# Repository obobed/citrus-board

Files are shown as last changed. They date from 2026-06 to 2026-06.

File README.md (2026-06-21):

# Citrus Board
A RP2350 based devboard with LiPO and HSTX support!

## Why I made this + features
I made this since I wanted an alternative to the mainstream RP2350/2040 boards (like the xiaos), but with support for the more niche features of the chip that aren't exposed on almost all of them, like HSTX ([page 1203](https://pip-assets.raspberrypi.com/categories/1214-rp2350/documents/RP-008373-DS-2-rp2350-datasheet.pdf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)), which allows you to easily add an external display (or even camera) without sacrificing a lot the small computing power of the small chip, or even LiPo support (although most boards have it (except for the Raspberry Pi Pico), many don't have a dedicated charging IC to both support the chip's usage and to charge the battery at the same time). Additionally, it has 26 pins, indicator LEDs for charging and power, the HSTX 22pin ribbon cable terminal (which can be used with libraries like [this](https://github.com/adafruit/Adafruit-DVI-HSTX) from Adafruit) and a debug connector that is exactly compatible with the oficial [Raspberry Pi Debug Probe
](https://www.raspberrypi.com/documentation/microcontrollers/debug-probe.html).

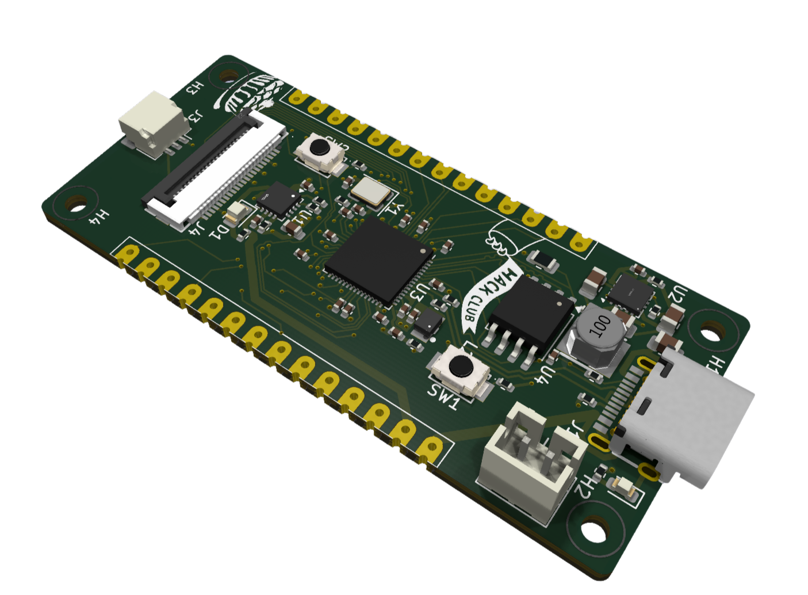
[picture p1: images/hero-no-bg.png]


## Repo Structure
* [/pcb](/pcb) - My KiCad design files
* [/production](/production) - Everything you need to manufacture your own! Includes gerbers, a bom and positioning files
* [/images](/images) - Images of my PCB and 3D view! (Zine is in [/zine](/zine))
* [/plots](/plots) - Schematic plot (SVG and PNG) and separate layer outlines in DXF format
* [/cad](/cad) - A step file of my PCB for reference when building projects around it
* [/bom](/bom) - My BOMs (like the below tables) stored in a CSV format

## Schematic
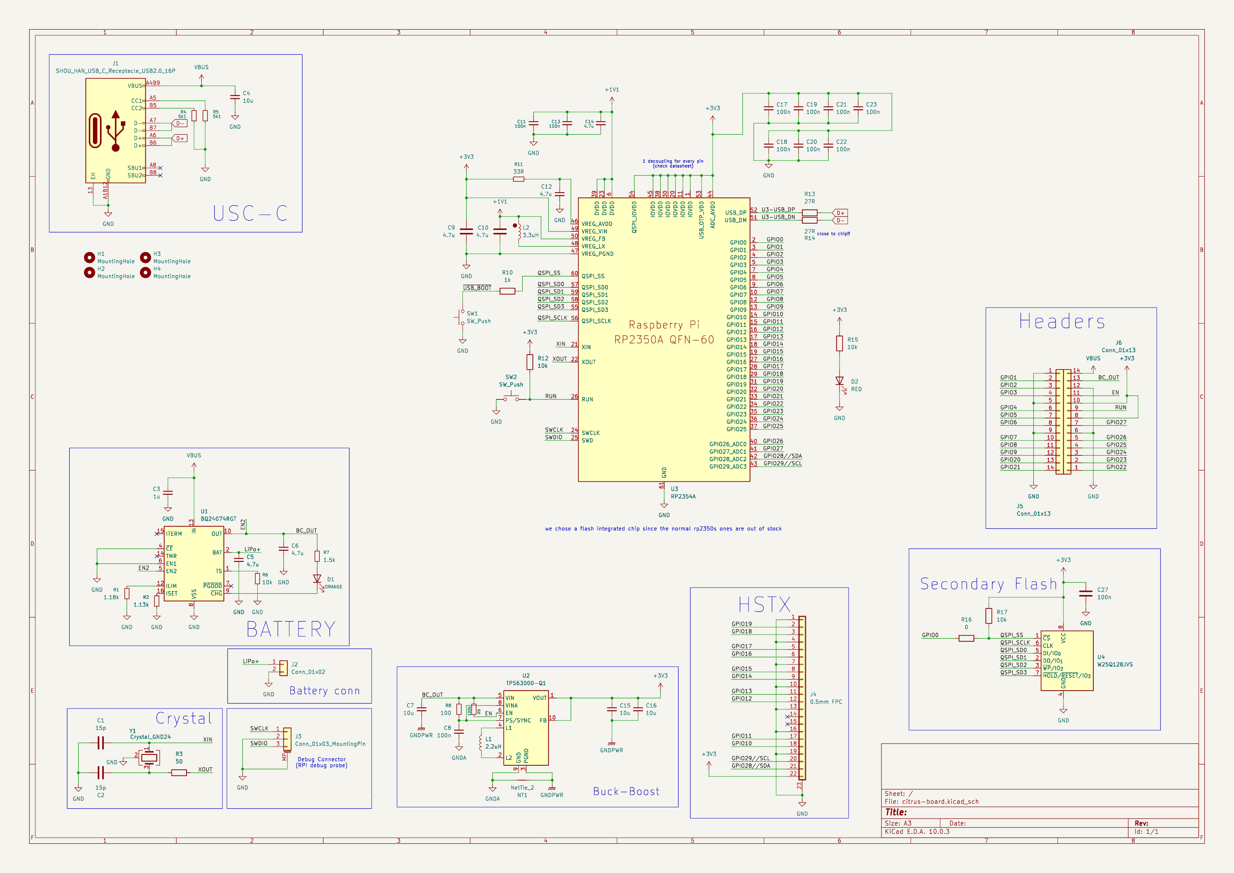
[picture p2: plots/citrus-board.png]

## PCB
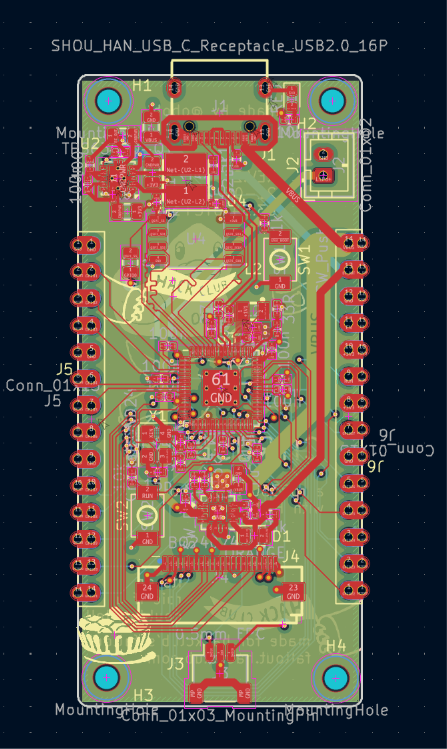
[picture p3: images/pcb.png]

## 3D View

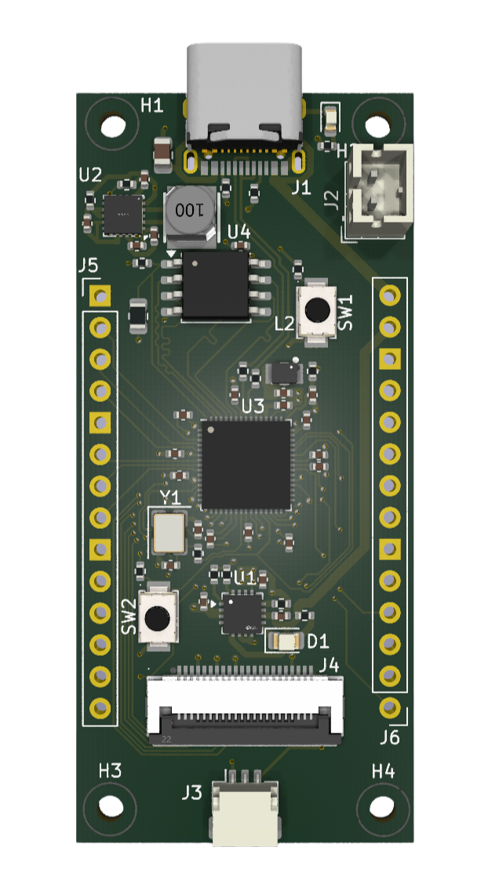
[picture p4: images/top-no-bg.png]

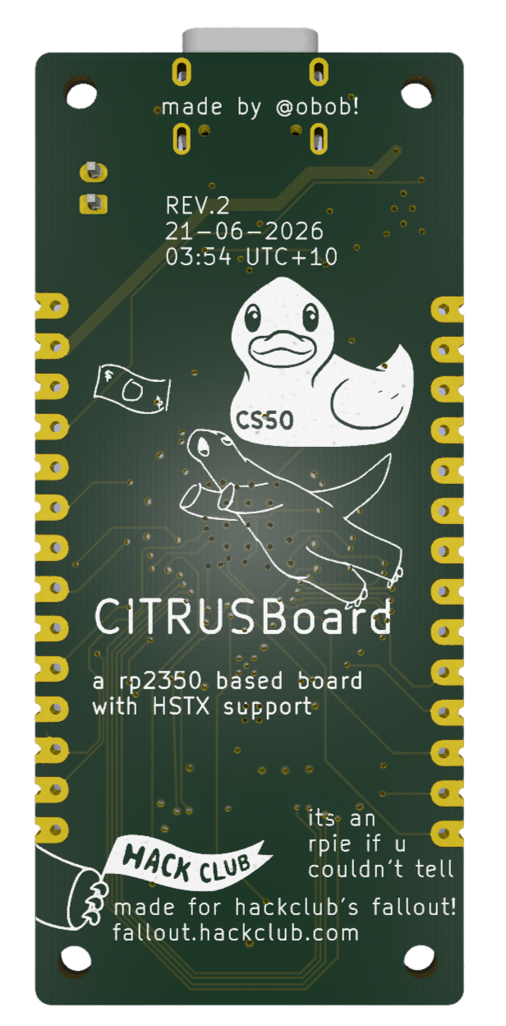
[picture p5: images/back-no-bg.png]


## Assembly
Welll this is a devboard, so there isn't much to assemble, but if you want to hand solder (definitely do not reccomend) instead of doing PCBA, follow these steps (my bom at the bottom accounts for using PCBA and not hand soldering)
Prerequisite:
* Purchase a stencil from JLCPCB alongside your order, and use the [LCSC BOM](/bom/component_bom.csv) to buy the separate parts from LCSC

1. Apply the paste
2. Place components
3. Use your preferred equipment (oven, hot-air gun or hotplate) to solder the board
4. Done!

(this section is here because the submission precheck kept giving me warning about this)

## BOM
### Component BOM
| Designator | Footprint | Quantity | Value | LCSC Part # | Total Cost (USD) |
|---|---|---|---|---|---|
| C1, C2 | 0402 | 2 | 15p | C1548 | 0.0088 |
| C10, C12, C14, C5, C6, C9 | 0402 | 6 | 4.7u | C23733 | 0.2328 |
| C11, C13, C17, C18, C19, C20, C21, C22, C23, C27, C8 | 0402 | 11 | 100n | C307331 | 0.0682 |
| C15, C16, C4, C7 | 0805 | 4 | 10u | C1713 | 1.6848 |
| C3 | 603 | 1 | 1u | C1592 | 0.0312 |
| D1 | 0805 | 1 | ORANGE | C2296 | 0.0304 |
| D2 | 0603 | 1 | RED | C2286 | 0.0144 |
| J1 | USB-C-SMD_TYPE-C-6PIN-2MD-073 | 1 | SHOU_HAN_USB_C_Receptacle_USB2.0_16P | | 0.2205 |
| J2 | JST_PH_B2B-PH-K_1x02_P2.00mm_Vertical | 1 | Conn_01x02 | C131337 | 0.1041 |
| J3 | JST_SH_SM03B-SRSS-TB_1x03-1MP_P1.00mm_Horizontal | 1 | Conn_01x03_MountingPin | C160389 | 1.3305 |
| J4 | CONN-SMD_AFC01-S22FCA-HF | 1 | 0.5mm FPC | C49260526 | 0.2614 |
| L1 | IND-SMD_L3.9-W3.9 | 1 | 2.2uH | C20416998 | 2.2494 |
| L2 | IND-SMD_L2.0-W1.6_AOTA-B201610S3R3-101-T | 1 | 3.3uH | C42411119 | 1.4085 |
| R1 | 0402 | 1 | 1.18k | C270651 | 0.01 |
| R10 | 0402 | 1 | 1k | C270651 | 0.0022 |
| R11 | 0402 | 1 | 33R | C25105 | 0.002 |
| R12, R15, R17, R6 | 0402 | 4 | 10k | C25744 | 0.0232 |
| R13, R14 | 0402 | 2 | 27R | C25100 | 0.02 |
| R16 | 0805 | 1 | 0 | C17477 | 0.006 |
| R2 | 0402 | 1 | 1.13k | C67014 | 0.018 |
| R3 | 0402 | 1 | 50 | C227387 | 0.016 |
| R4, R5 | 0402 | 2 | 5k1 | C25905 | 0.0036 |
| R7 | 0402 | 1 | 1.5k | C25867 | 0.0022 |
| R8 | 0402 | 1 | 100 | C25076 | 0.0024 |
| R9 | 0402 | 1 | 100k | C25741 | 0.0078 |
| SW1, SW2 | SW-SMD_L3.9-W3.0-P4.45 | 2 | SW_Push | C720477 | 0.2208 |
| U1 | VQFN-16-1EP_3x3mm_P0.5mm_EP1.6x1.6mm | 1 | BQ24074RGT | C54313 | 4.7728 |
| U2 | Texas_DRC0010J_ThermalVias | 1 | TPS63000-Q1 | C28060 | 3.5514 |
| U3 | RP2350-QFN-60-1EP_7x7_P0.4mm_EP3.4x3.4mm_ThermalVias | 1 | RP2354A | C41378174 | 2.678 |
| U4 | SOIC-8_5.3x5.3mm_P1.27mm | 1 | W25Q128JVS | C97521 | 4.8534 |
| Y1 | Crystal_SMD_3225-4Pin_3.2x2.5mm | 1 | Crystal_GND24 | C20625731 | 1.4655 |
|||||||
| Total | | | | | 25.3003 |

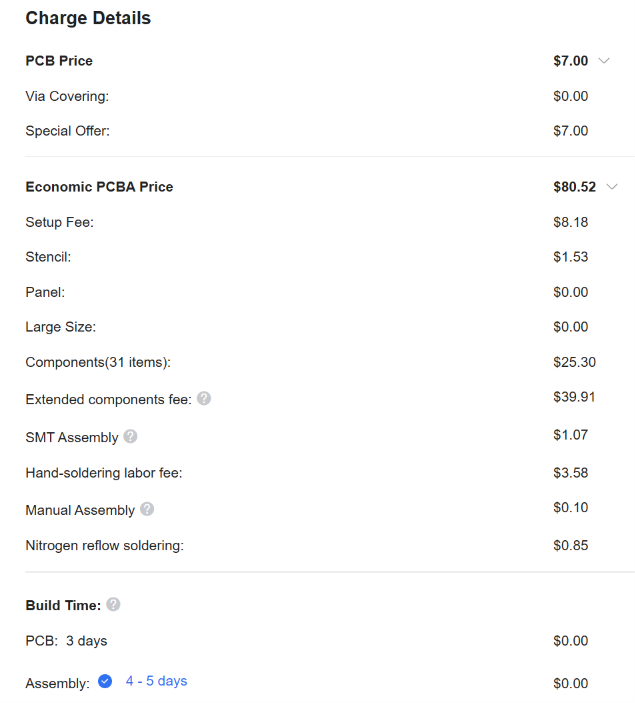
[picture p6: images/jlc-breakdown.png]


### Overall BOM
| Item | Cost (USD) | Notes |
|---|---|---|
| PCB | $7 | |
| Castellated Edges | $37.70 | Not strictly required, see note 2 [here](https://jlcpcb.com/help/article/what-is-castellated-holes). If you want to save on costs, it is not necessary, but will result in a slightly lower quality finish. |
| PCB Shipping | $1.50 | |
| PCBA | $80.72 | |
||||
| Total | $89.22 ||

## Zine!!
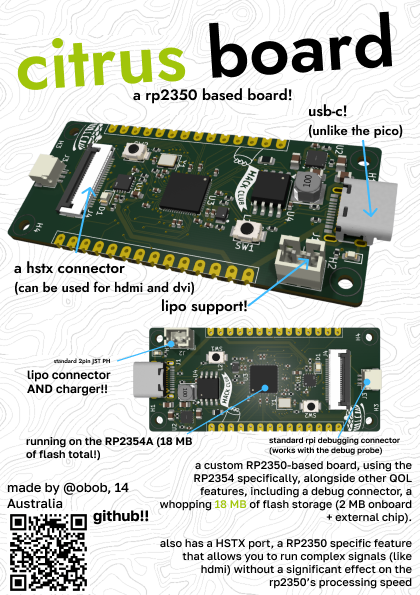
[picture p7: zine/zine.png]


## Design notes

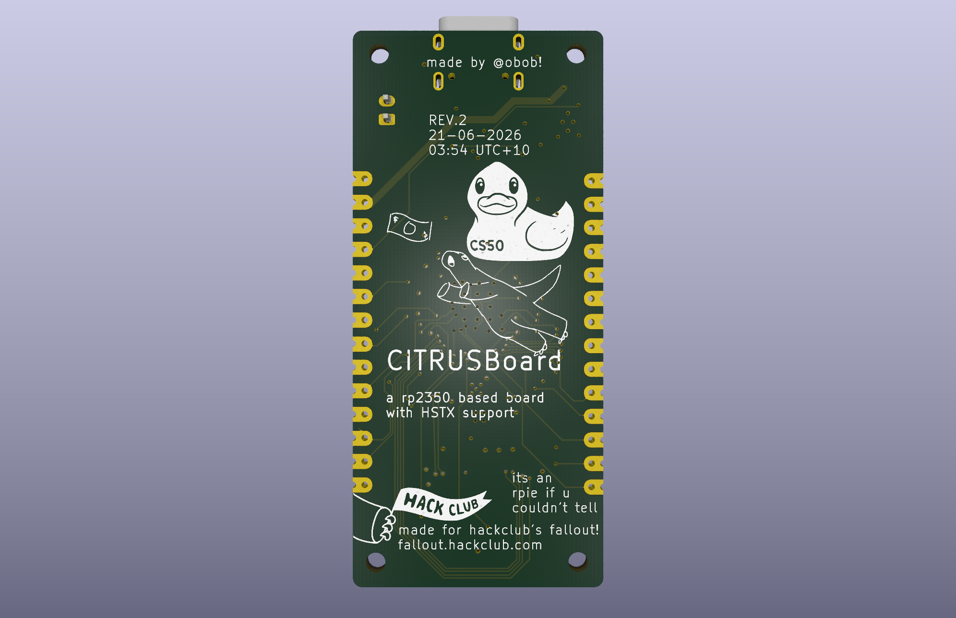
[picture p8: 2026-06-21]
images/back.png

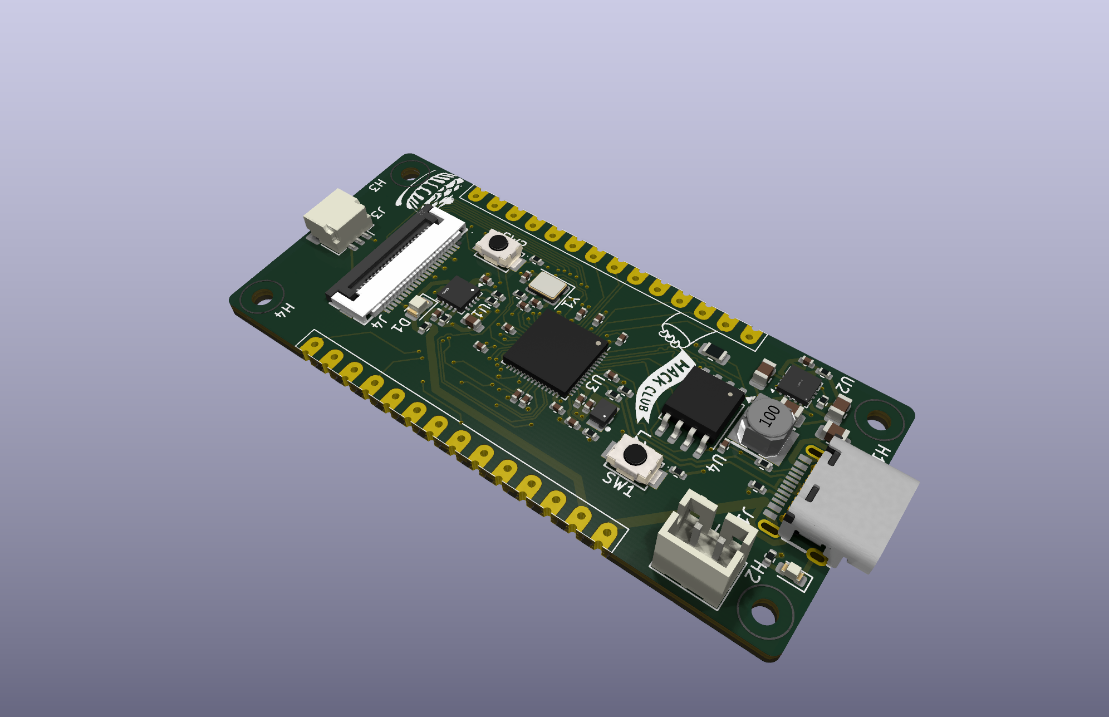
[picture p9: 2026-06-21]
images/hero.png

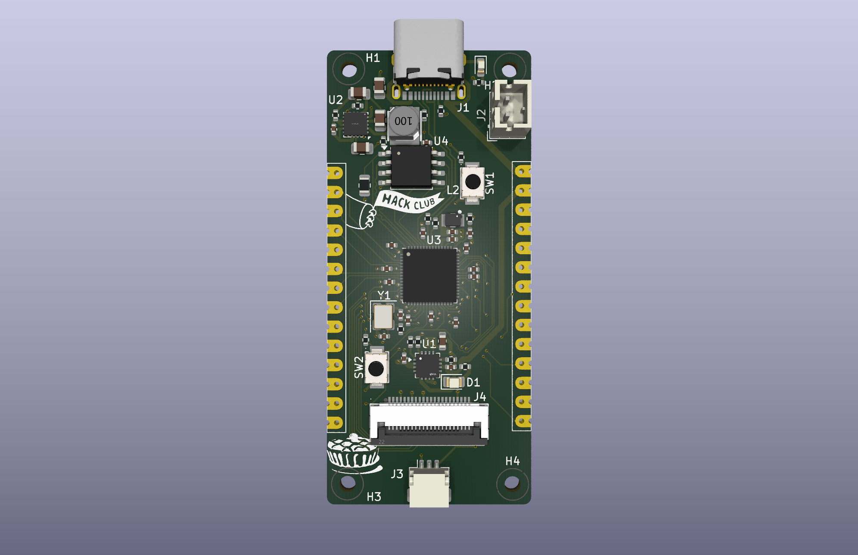
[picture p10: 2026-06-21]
images/front.png

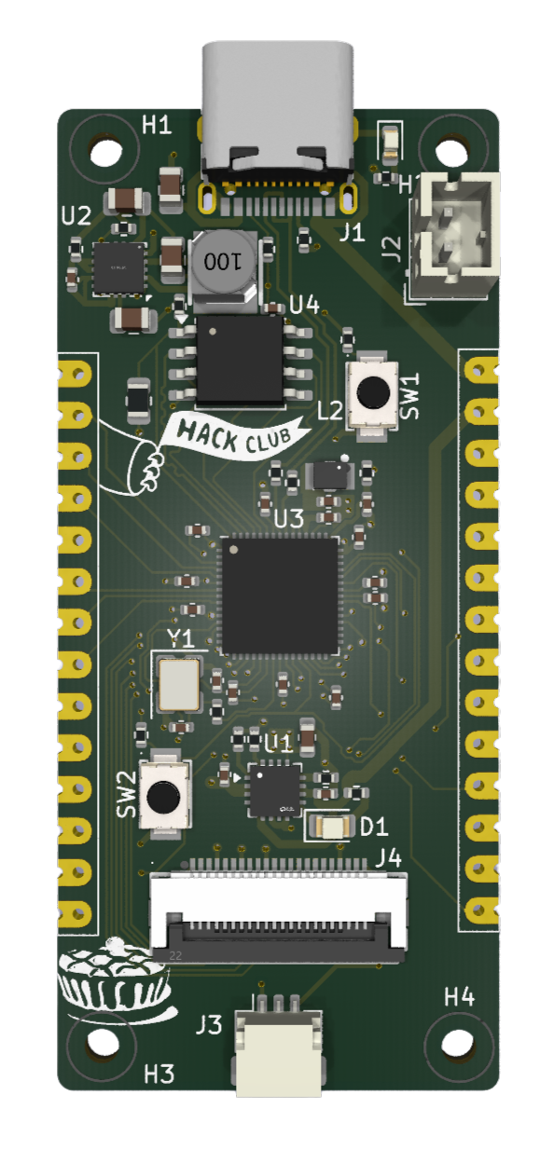
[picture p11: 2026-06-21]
images/front-no-bg.png

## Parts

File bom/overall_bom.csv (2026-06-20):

Item | Cost (USD)
PCB | $7
PCB Shipping | $1.50
PCBA | $80.72
Total | $89

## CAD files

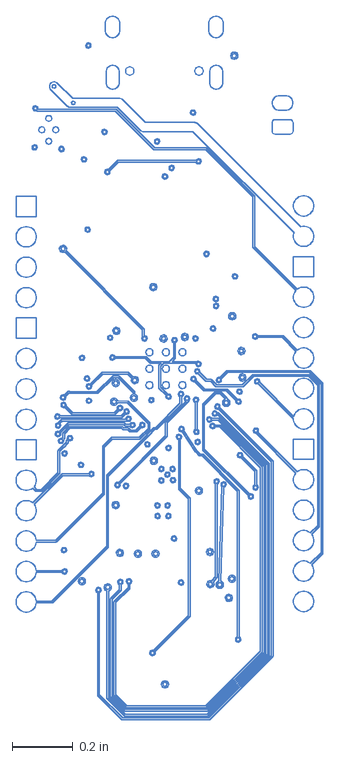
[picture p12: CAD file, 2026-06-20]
plots/citrus-board-B_Cu.dxf
1.01 x 2.31 in

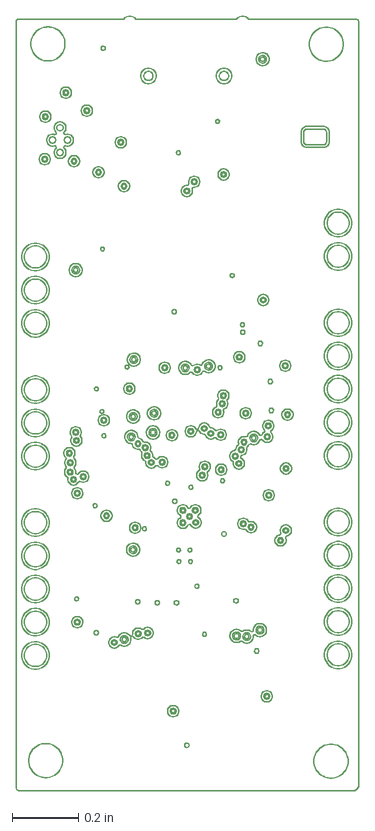
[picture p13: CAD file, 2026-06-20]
plots/citrus-board-In1_Cu.dxf
1.03 x 2.33 in

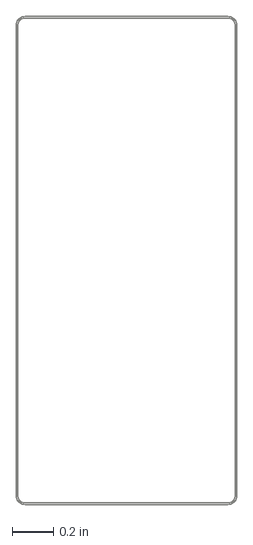
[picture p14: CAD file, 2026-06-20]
plots/citrus-board-Edge_Cuts.dxf
1.07 x 2.37 in

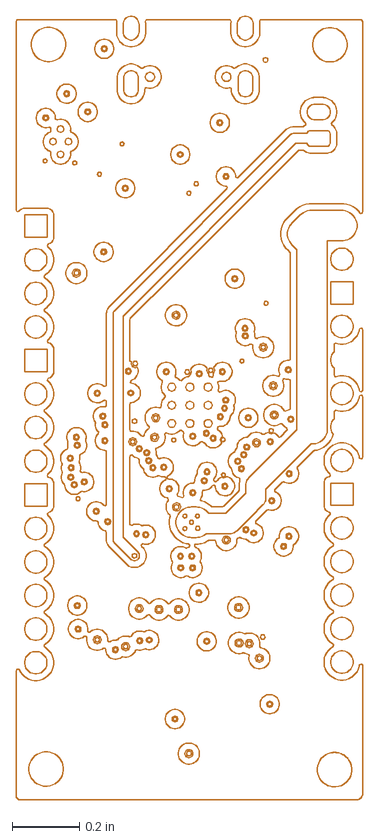
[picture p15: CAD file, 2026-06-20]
plots/citrus-board-In2_Cu.dxf
1.03 x 2.33 in

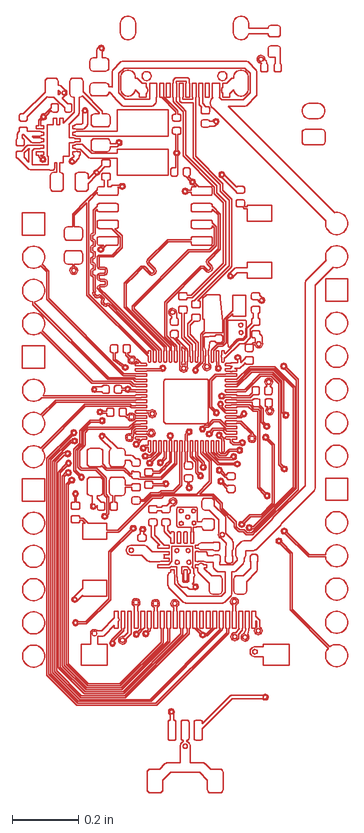
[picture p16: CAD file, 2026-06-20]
plots/citrus-board-F_Cu.dxf
0.997 x 2.34 in

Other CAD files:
plots/citrus-board-B_Mask.dxf
plots/citrus-board-B_Paste.dxf
plots/citrus-board-B_Silkscreen.dxf
plots/citrus-board-F_Mask.dxf
plots/citrus-board-F_Paste.dxf
plots/citrus-board-F_Silkscreen.dxf

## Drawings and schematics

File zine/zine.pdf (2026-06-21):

## usb-c!

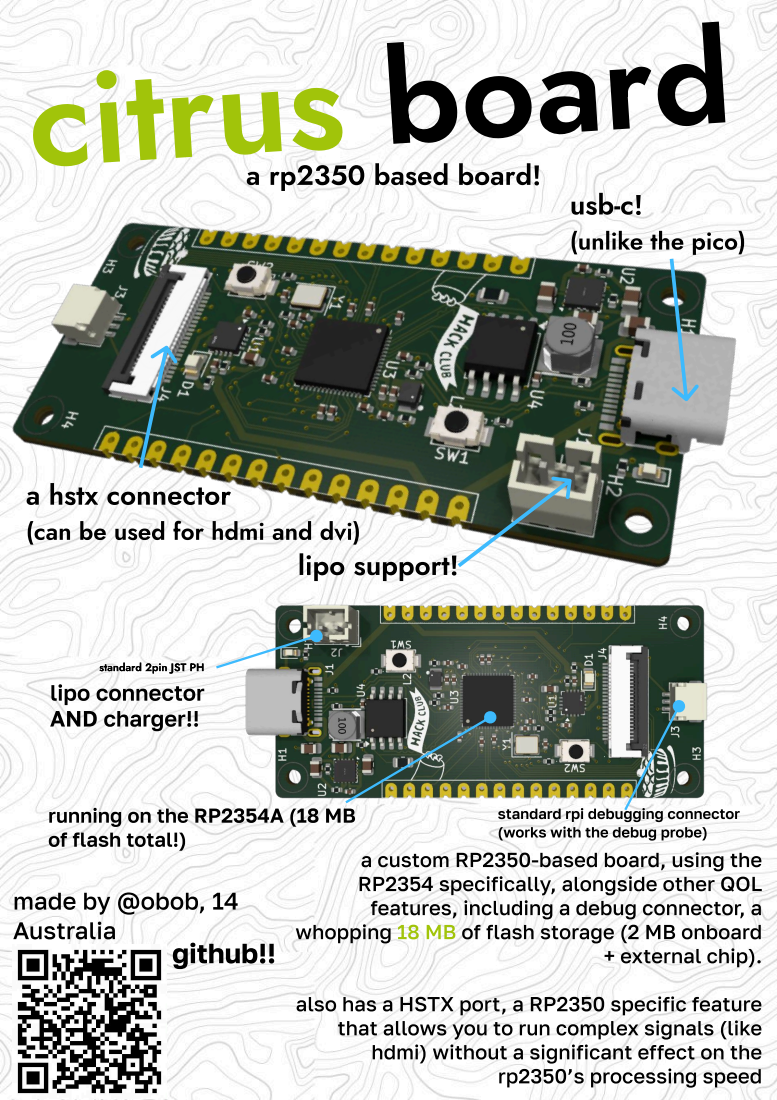
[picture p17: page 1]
lipo support!; github!!; + external chip).; rp2350’s processing speed

citrus board a rp2350 based board!

(unlike the pico)

a hstx connector
(can be used for hdmi and dvi)

standard 2pin JST PH
lipo connector
AND charger!!

running on the RP2354A (18 MB
of flash total!)

standard rpi debugging connector
(works with the debug probe)

a custom RP2350-based board, using the
RP2354 specifically, alongside other QOL
features, including a debug connector, a

made by @obob, 14
Australia

whopping 18 MB of flash storage (2 MB onboard

also has a HSTX port, a RP2350 specific feature
that allows you to run complex signals (like
hdmi) without a significant effect on the

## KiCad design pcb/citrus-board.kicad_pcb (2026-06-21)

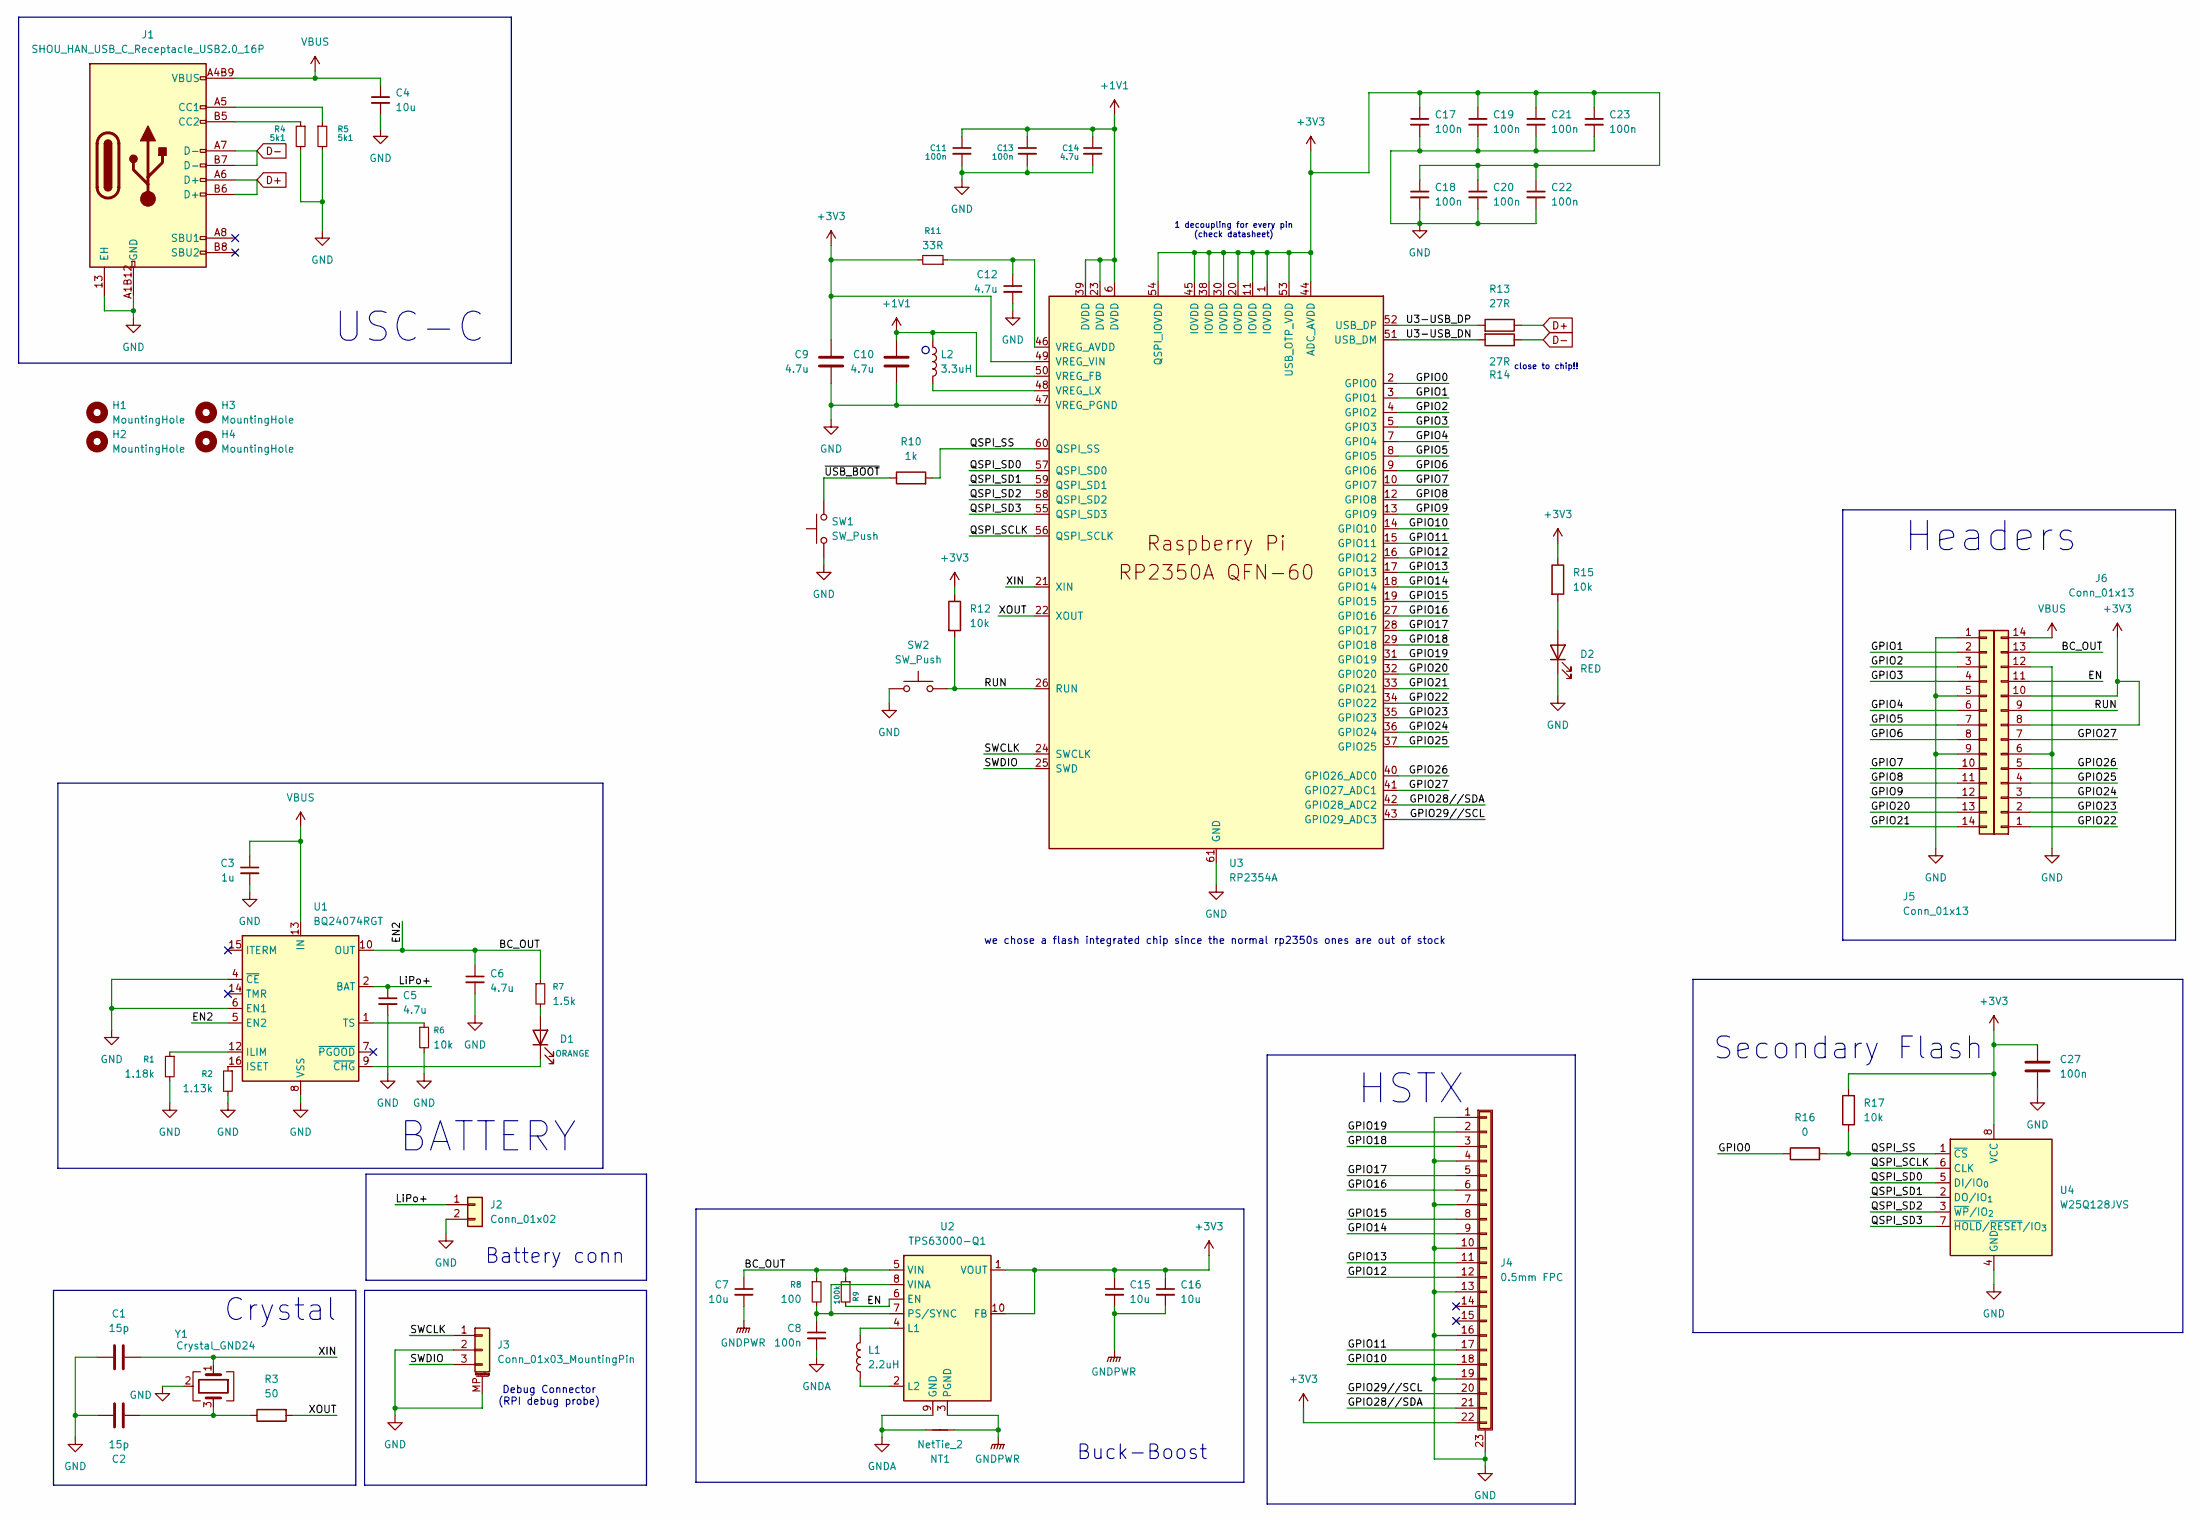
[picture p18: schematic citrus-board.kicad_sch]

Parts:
C1, C2: 15p; C_0402_1005Metric; LCSC Part # C1548
C3: 1u; C_0603_1608Metric; LCSC Part # C1592
C4, C7, C15, C16: 10u; C_0805_2012Metric; LCSC Part # C1713
C5, C6, C9, C10, C12, C14: 4.7u; C_0402_1005Metric; LCSC Part # C23733
C8, C11, C13, C17, C18, C19, C20, C21, C22, C23, C27: 100n; C_0402_1005Metric; LCSC Part # C307331
D1: ORANGE; LED_0805_2012Metric; LCSC Part # C2296
D2: RED; LED_0603_1608Metric; LCSC Part # C2286
H1, H2, H3, H4: MountingHole; MountingHole_2.1mm
J1: SHOU_HAN_USB_C_Receptacle_USB2.0_16P; USB-C-SMD_TYPE-C-6PIN-2MD-073; LCSC Part # C2765186
J2: Conn_01x02; JST_PH_B2B-PH-K_1x02_P2.00mm_Vertical; LCSC Part # C131337
J3: Conn_01x03_MountingPin; JST_SH_SM03B-SRSS-TB_1x03-1MP_P1.00mm_Horizontal; LCSC Part # C160389
J4: 0.5mm FPC; CONN-SMD_AFC01-S22FCA-HF; LCSC Part # C49260526
J5, J6: Conn_01x13; Conn_01x14_Castellated
L1: 2.2uH; IND-SMD_L3.9-W3.9; LCSC Part # C20416998
L2: 3.3uH; IND-SMD_L2.0-W1.6_AOTA-B201610S3R3-101-T; LCSC Part # C42411119
NT1: NetTie_2; NetTie-2_SMD_Pad0.5mm
R1: 1.18k; R_0402_1005Metric; LCSC Part # C270651
R2: 1.13k; R_0402_1005Metric; LCSC Part # C67014
R3: 50; R_0402_1005Metric; LCSC Part # C227387
R4, R5: 5k1; R_0402_1005Metric; LCSC Part # C25905
R6, R12, R15, R17: 10k; R_0402_1005Metric; LCSC Part # C25744
R7: 1.5k; R_0402_1005Metric; LCSC Part # C25867
R8: 100; R_0402_1005Metric; LCSC Part # C25076
R9: 100k; R_0402_1005Metric; LCSC Part # C25741
R10: 1k; R_0402_1005Metric; LCSC Part # C270651
R11: 33R; R_0402_1005Metric; LCSC Part # C25105
R13, R14: 27R; R_0402_1005Metric; LCSC Part # C25100
R16: 0; R_0805_2012Metric; LCSC Part # C17477
SW1, SW2: SW_Push; SW-SMD_L3.9-W3.0-P4.45; LCSC Part # C720477
U1: BQ24074RGT; VQFN-16-1EP_3x3mm_P0.5mm_EP1.6x1.6mm; LCSC Part # C54313
U2: TPS63000-Q1; Texas_DRC0010J_ThermalVias; LCSC Part # C28060
U3: RP2354A; RP2350-QFN-60-1EP_7x7_P0.4mm_EP3.4x3.4mm_ThermalVias; LCSC Part # C41378174
U4: W25Q128JVS; SOIC-8_5.3x5.3mm_P1.27mm; LCSC Part # C97521
Y1: Crystal_GND24; Crystal_SMD_3225-4Pin_3.2x2.5mm; LCSC Part # C20625731

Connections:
+1V1: C10.1, C11.1, C13.1, C14.1, L2.1, U3.6 (DVDD), U3.23 (DVDD), U3.39 (DVDD), U3.50 (VREG_FB)
+3V3: C9.1, C15.1, C16.1, C17.1, C18.1, C19.1, C20.1, C21.1, C22.1, C23.1, C27.1, J4.22, J6.8, J6.10, R11.2, R12.1, R15.1, R17.2, U2.1 (VOUT), U2.10 (FB), U3.1 (IOVDD), U3.11 (IOVDD), U3.20 (IOVDD), U3.30 (IOVDD), U3.38 (IOVDD), U3.44 (ADC_AVDD), U3.45 (IOVDD), U3.49 (VREG_VIN), U3.53 (USB_OTP_VDD), U3.54 (QSPI_IOVDD), U4.8 (VCC)
/BC_OUT: C6.1, C7.1, J6.13, R7.1, R8.1, R9.1, U1.5 (EN2), U1.10 (OUT), U1.11 (OUT), U2.5 (VIN)
/EN: J6.11, R9.2, U2.6 (EN)
/GPIO0: R16.1, U3.2 (GPIO0)
/GPIO1: J5.2, U3.3 (GPIO1)
/GPIO2: J5.3, U3.4 (GPIO2)
/GPIO3: J5.4, U3.5 (GPIO3)
/GPIO4: J5.6, U3.7 (GPIO4)
/GPIO5: J5.7, U3.8 (GPIO5)
/GPIO6: J5.8, U3.9 (GPIO6)
/GPIO7: J5.10, U3.10 (GPIO7)
/GPIO8: J5.11, U3.12 (GPIO8)
/GPIO9: J5.12, U3.13 (GPIO9)
/GPIO10: J4.18, U3.14 (GPIO10)
/GPIO11: J4.17, U3.15 (GPIO11)
/GPIO12: J4.12, U3.16 (GPIO12)
/GPIO13: J4.11, U3.17 (GPIO13)
/GPIO14: J4.9, U3.18 (GPIO14)
/GPIO15: J4.8, U3.19 (GPIO15)
/GPIO16: J4.6, U3.27 (GPIO16)
/GPIO17: J4.5, U3.28 (GPIO17)
/GPIO18: J4.3, U3.29 (GPIO18)
/GPIO19: J4.2, U3.31 (GPIO19)
/GPIO20: J5.13, U3.32 (GPIO20)
/GPIO21: J5.14, U3.33 (GPIO21)
/GPIO22: J6.1, U3.34 (GPIO22)
/GPIO23: J6.2, U3.35 (GPIO23)
/GPIO24: J6.3, U3.36 (GPIO24)
/GPIO25: J6.4, U3.37 (GPIO25)
/GPIO26: J6.5, U3.40 (GPIO26_ADC0)
/GPIO27: J6.7, U3.41 (GPIO27_ADC1)
/GPIO28//SDA: J4.21, U3.42 (GPIO28_ADC2)
/GPIO29//SCL: J4.20, U3.43 (GPIO29_ADC3)
/LiPo+: C5.1, J2.1, U1.2 (BAT), U1.3 (BAT)
/QSPI_SCLK: U3.56 (QSPI_SCLK), U4.6 (CLK)
/QSPI_SD0: U3.57 (QSPI_SD0), U4.5 (DI/IO_{0})
/QSPI_SD1: U3.59 (QSPI_SD1), U4.2 (DO/IO_{1})
/QSPI_SD2: U3.58 (QSPI_SD2), U4.3 (~WP/IO_{2})
/QSPI_SD3: U3.55 (QSPI_SD3), U4.7 (~HOLD/~RESET/IO_{3})
/QSPI_SS: R10.2, R16.2, R17.1, U3.60 (QSPI_SS), U4.1 (~CS)
/RUN: J6.9, R12.2, SW2.2, U3.26 (RUN)
/SWCLK: J3.1, U3.24 (SWCLK)
/SWDIO: J3.3, U3.25 (SWD)
/U3-USB_DN: R14.2, U3.51 (USB_DM)
/U3-USB_DP: R13.2, U3.52 (USB_DP)
/XIN: C1.2, U3.21 (XIN), Y1.1
/XOUT: R3.2, U3.22 (XOUT)
/~USB_BOOT: R10.1, SW1.2
D+: J1.A6 (D+), J1.B6 (D+), R13.1
D-: J1.A7 (D-), J1.B7 (D-), R14.1
GND: C1.1, C2.1, C3.2, C4.2, C5.2, C6.2, C9.2, C10.2, C11.2, C12.2, C13.2, C14.2, C17.2, C18.2, C19.2, C20.2, C21.2, C22.2, C23.2, C27.2, D2.1 (K), J1.13 (EH), J1.14 (EH), J1.A1B12 (GND), J1.B1A12 (GND), J2.2, J3.2, J3.MP (MountPin), J4.1, J4.4, J4.7, J4.10, J4.13, J4.16, J4.19, J4.23 (Shield), J4.24 (Shield), J5.1, J5.5, J5.9, J6.6, J6.12, R1.2, R2.2, R4.2, R5.2, R6.2, SW1.1, SW2.1, U1.4 (~CE), U1.6 (EN1), U1.8 (VSS), U1.17 (VSS), U3.47 (VREG_PGND), U3.61 (GND), U4.4 (GND), Y1.2 (G), Y1.4 (G)
GNDA: C8.2, NT1.1, U2.9 (GND)
GNDPWR: C7.2, C15.2, C16.2, NT1.2, U2.3 (PGND), U2.11 (PGND)
unnamed: C2.2, R3.1, Y1.3
unnamed: D1.2 (A), R7.2
unnamed: D1.1 (K), U1.9 (~CHG)
unnamed: D2.2 (A), R15.2
unnamed: J1.A5 (CC1), R5.1
unnamed: J1.B5 (CC2), R4.1
unnamed: R1.1, U1.12 (ILIM)
unnamed: R2.1, U1.16 (ISET)
unnamed: R6.1, U1.1 (TS)
unnamed: L1.2, U2.4 (L1)
unnamed: L1.1, U2.2 (L2)
unnamed: C8.1, R8.2, U2.7 (PS/SYNC), U2.8 (VINA)
unnamed: C12.1, R11.1, U3.46 (VREG_AVDD)
unnamed: L2.2, U3.48 (VREG_LX)
VBUS: C3.1, C4.1, J1.A4B9 (VBUS), J1.B4A9 (VBUS), J6.14, U1.13 (IN)

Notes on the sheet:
HSTX
USC-C
Headers
Crystal
1 decoupling for every pin (check datasheet)
close to chip!!
Debug Connector (RPI debug probe)
Buck-Boost
Battery conn
we chose a flash integrated chip since the normal rp2350s ones are out of stock
Secondary Flash
BATTERY

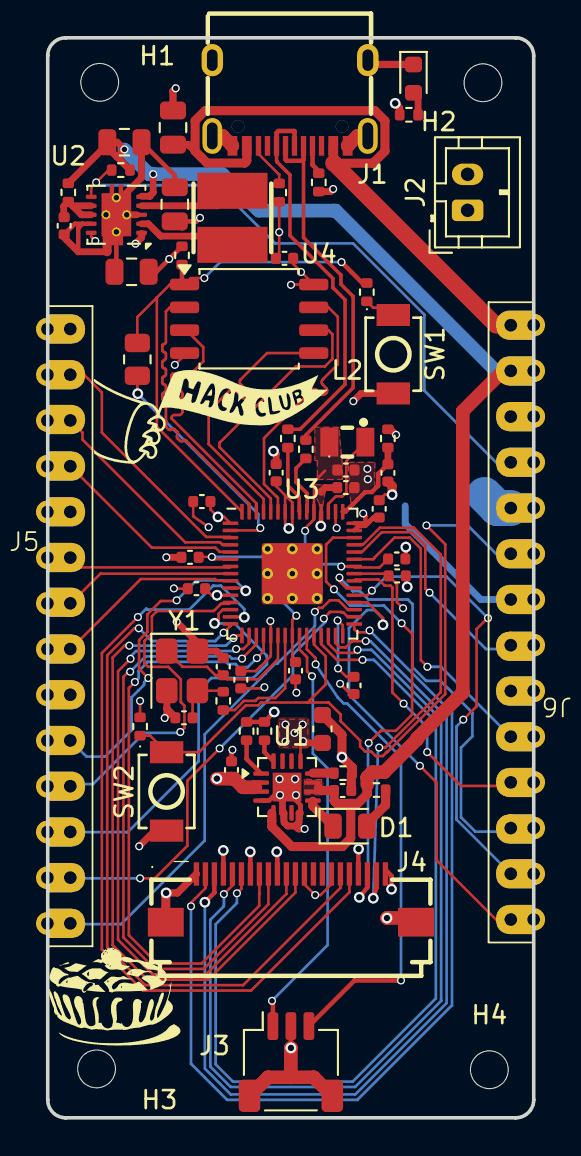
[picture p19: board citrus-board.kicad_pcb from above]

Board: 4 copper layers, 27.0 x 60.0 mm, 63 parts (0 on the bottom side), 69 nets.

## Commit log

2026-06-17 finish schema!
    todo:
    pcb
    clean up folders
    [citrus-board.kicad_pcb, citrus-board.kicad_sch]
2026-06-20 finish routing
    [citrus-board.kicad_pcb, citrus-board.kicad_sch]
2026-06-20 zine + rotate debug connector
    [citrus-board.kicad_pcb]
2026-06-20 update fields + production export
    [citrus-board.kicad_pcb, citrus-board.kicad_sch]
2026-06-20 fillets? never heard of er
    [citrus-board.kicad_pcb]
2026-06-20 oop forgot to save :sob:
    [citrus-board.kicad_pcb]
2026-06-20 images + restructure
    [citrus-board-B_Cu.dxf, citrus-board-B_Mask.dxf, citrus-board-B_Paste.dxf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]
2026-06-20 no boms?? also buns ahh gitignore
    [bom.csv, component_bom.csv, designators.csv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]
2026-06-21 castellated holes + better silkscreen + new images
    [citrus-board.kicad_pcb, citrus-board.kicad_sch]
2026-06-21 fix drc and better readme
    [citrus-board.kicad_pcb, designators.csv, positions.csv]
2026-06-21 README (assembly)
2026-06-21 hopefully the fallout precheck picks up on this?
    [citrus-board.kicad_pcb, positions.csv]
2026-06-21 woah crazy it did actually
    [bom.csv, designators.csv, positions.csv]
